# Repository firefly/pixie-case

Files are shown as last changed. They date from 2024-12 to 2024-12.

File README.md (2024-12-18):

Firefly Pixie: Case
===================

Clam Shell
----------

A simple two-part case, meant to be easy to assemble and mass
produce, providing full protection to the PCB, display and buttons.

Harness
-------

The harness is meant to be the simplest MVP of cases, designed to
be easy to assemble and disassemble to swap out boards, replace
screens and test basic components like the buttons and USB-C port
for durability.

It provides sufficient protection to the PCB, display and buttons
for development purposes.

<p align="center">
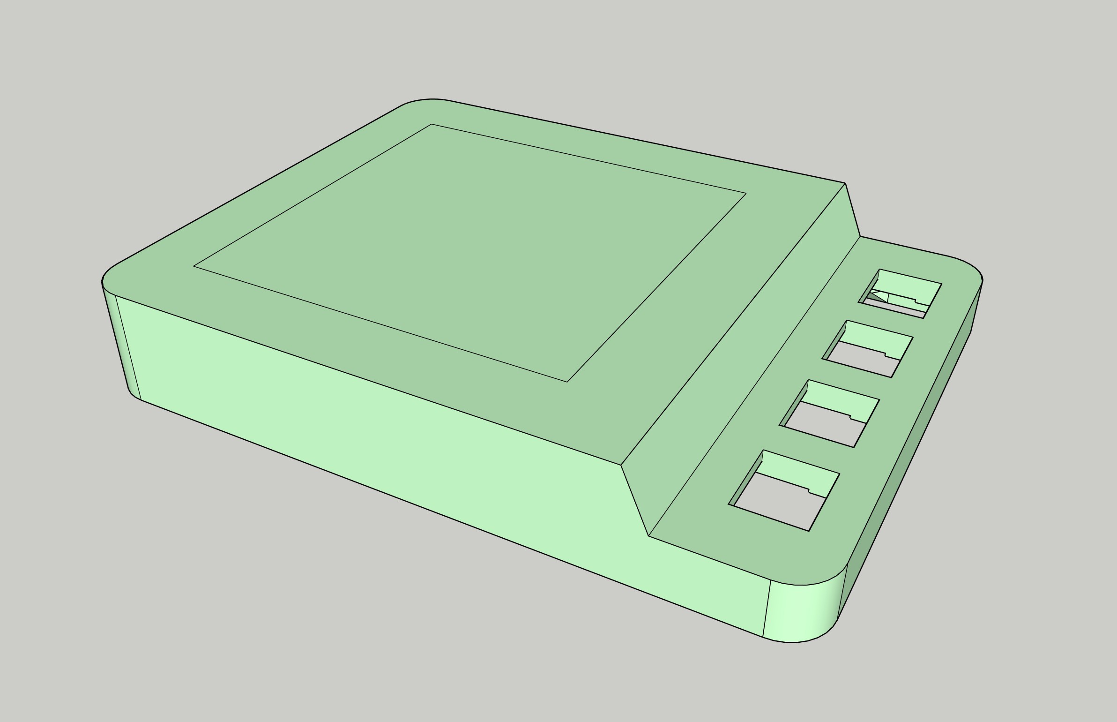
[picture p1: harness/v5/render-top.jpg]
Harness Top View
  
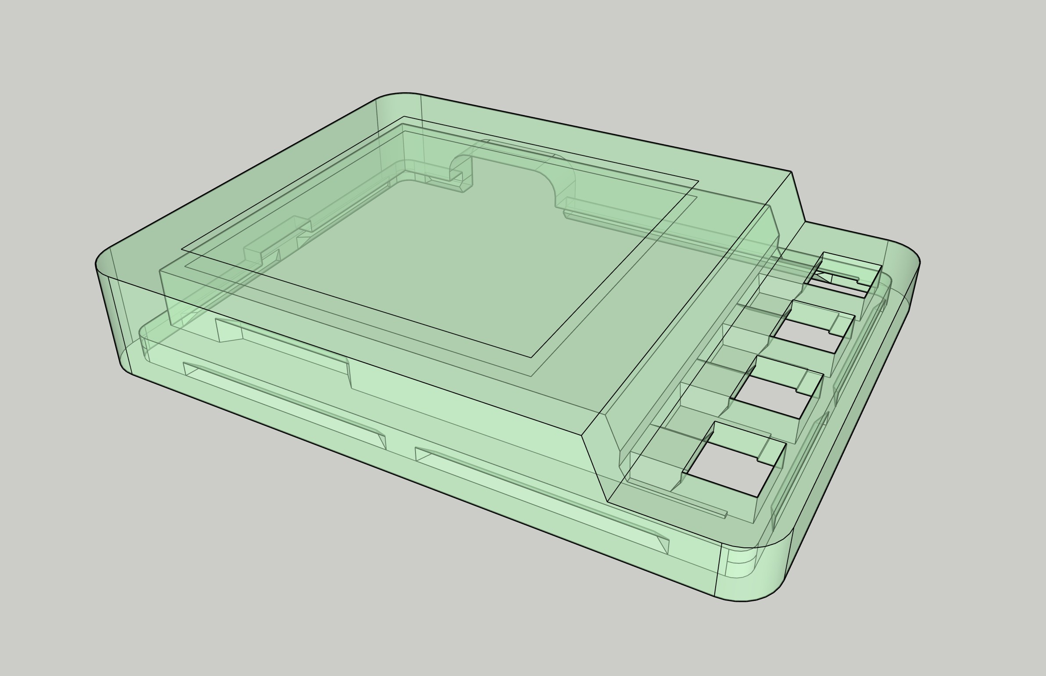
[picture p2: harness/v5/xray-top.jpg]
Harness Top X-ray View
  
</p>

<p align="center">
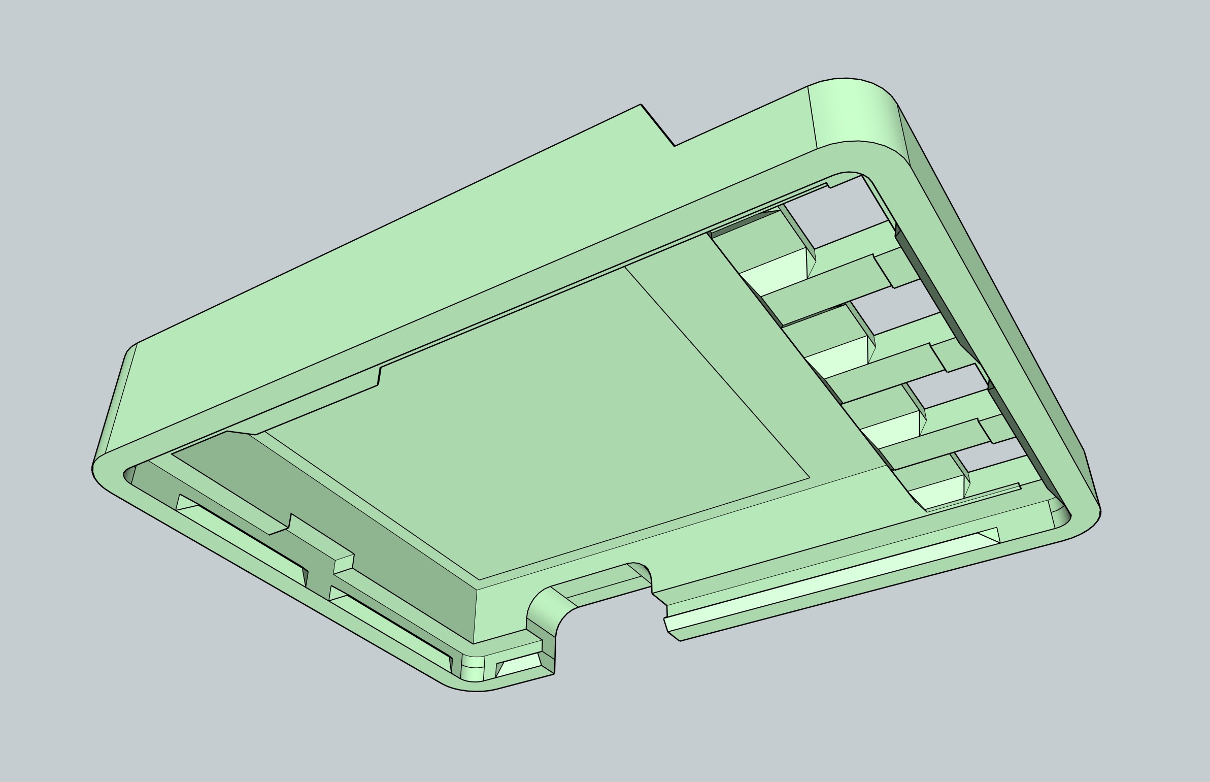
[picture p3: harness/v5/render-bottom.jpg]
Harness Bottom View
  
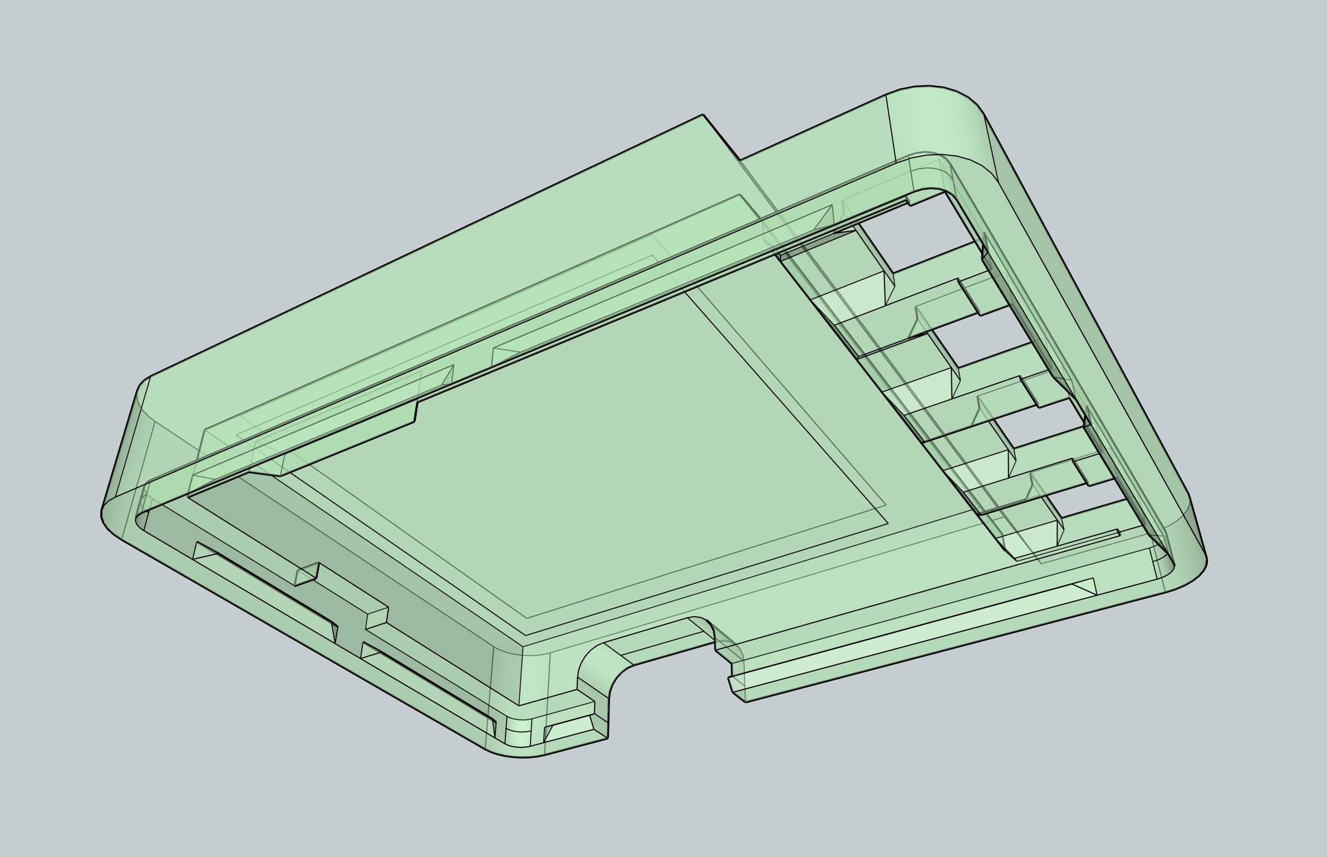
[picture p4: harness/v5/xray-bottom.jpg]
Harness Bottom X-ray View
  
</p>

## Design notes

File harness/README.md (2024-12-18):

Pixie Harness
=============

The Harness is a simple snap-fit case designed to provide minimum
viable protection and operation for devlopers to work with the
device until a more firm case can be designed.

The hardness is 3D printed in 8001 clear resin and snap-fits the
LCD and PCB.

The STL files are prepared for printing, with the `-opaque` variant
having the screen area knocked-out so that it can be printed in an
opaque material with the display still visible.

Renders
-------

<p align="center">
  Harness Top View
  Harness Top X-ray View
</p>

<p align="center">
  Harness Bottom View
  Harness Bottom X-ray View
</p>

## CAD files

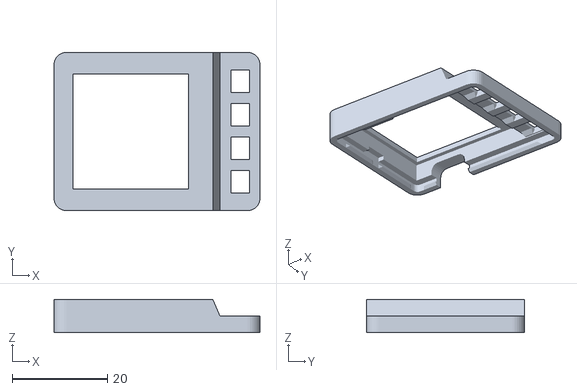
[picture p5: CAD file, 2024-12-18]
harness/v5/harness-opaque.stl
43.2 x 33.2 x 7.00

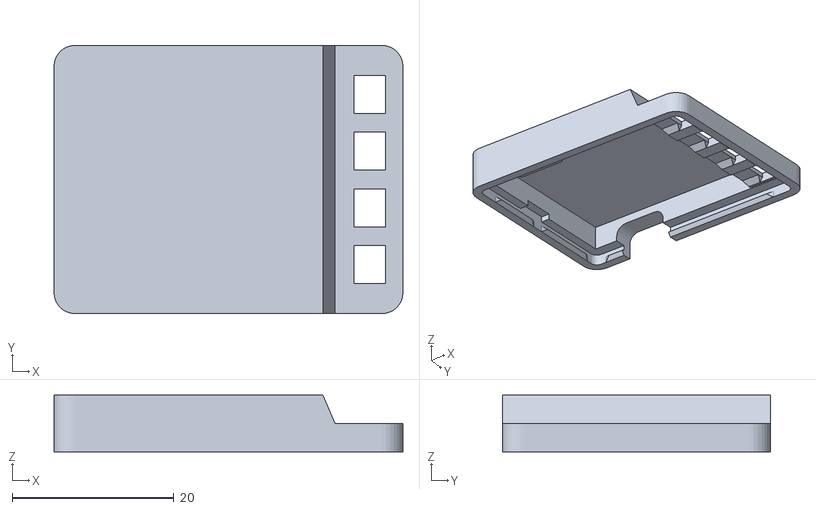
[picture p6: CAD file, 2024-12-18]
harness/v5/harness.stl
43.2 x 33.2 x 7.00

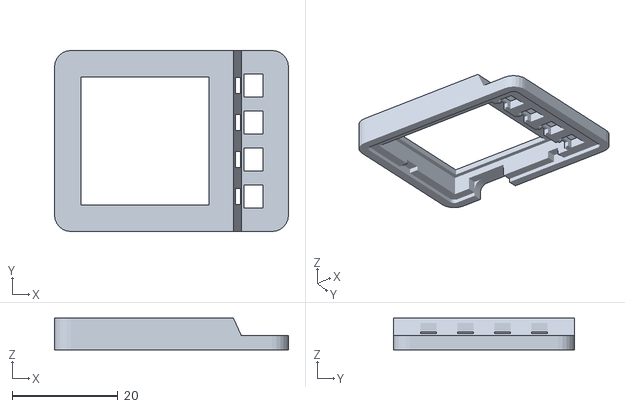
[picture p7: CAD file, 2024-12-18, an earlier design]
harness/v1/harness-opaque.stl
44.2 x 34.2 x 6.00

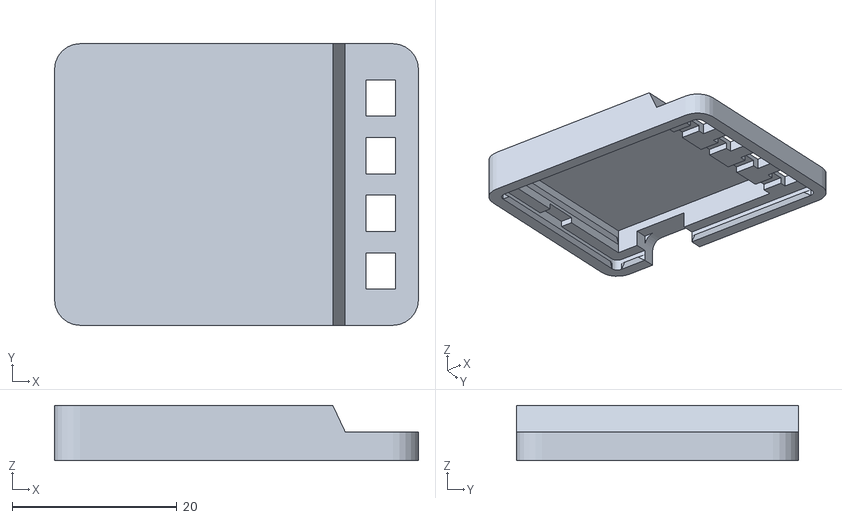
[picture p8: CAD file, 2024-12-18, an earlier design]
harness/v2/harness.stl
44.2 x 34.2 x 6.70

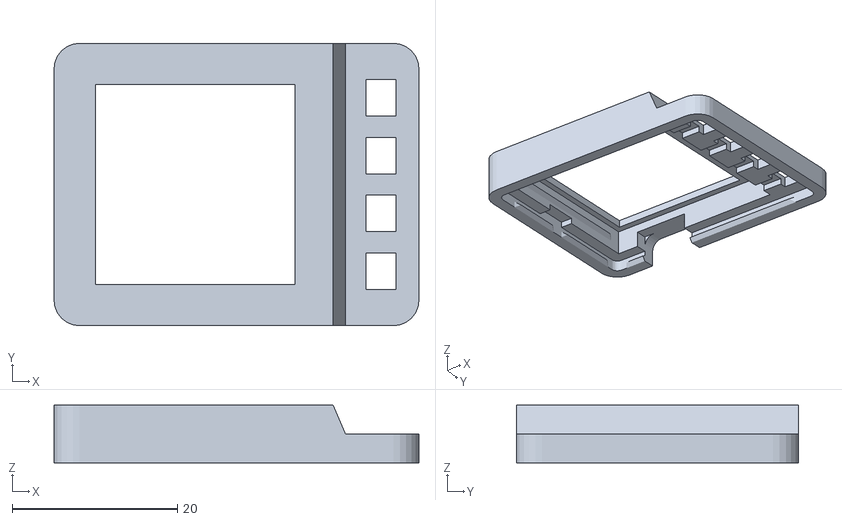
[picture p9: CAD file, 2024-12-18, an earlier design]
harness/v3/harness-opaque.stl
44.2 x 34.2 x 7.00

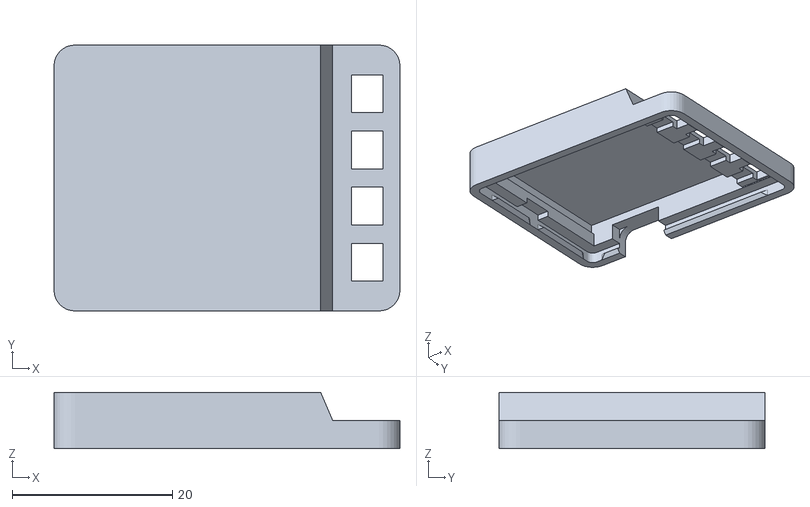
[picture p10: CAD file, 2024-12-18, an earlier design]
harness/v4/harness.stl
43.2 x 33.2 x 7.00

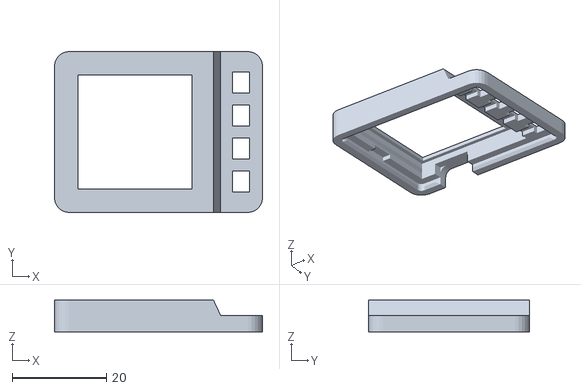
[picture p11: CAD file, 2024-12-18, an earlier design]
harness/v2/harness-opaque.stl
44.2 x 34.2 x 6.70

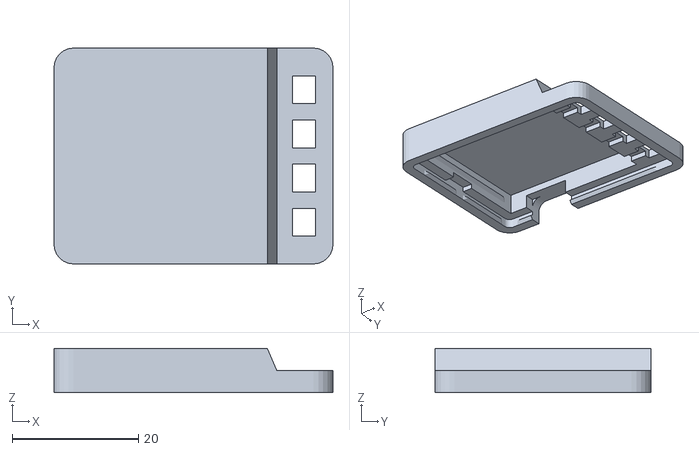
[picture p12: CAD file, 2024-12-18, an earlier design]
harness/v3/harness.stl
44.2 x 34.2 x 7.00

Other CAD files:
harness/v4/harness-opaque.stl
clamshell/clamshell.skp
harness/v1/harness.skp
harness/v2/harness.skp
harness/v3/harness.skp
harness/v4/harness.skp
harness/v5/harness.skp

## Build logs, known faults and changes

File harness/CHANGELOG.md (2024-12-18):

Changelog
=========

Since SketchUP files don't diff well, this log serves as a history of
the changes made between harness versions.

v5; 2024-10-06
--------------

- Remove display end retaining ledge and add display retaining nib

v4; 2024-08-24
--------------

- Added deeper retaining ledge.
- Increased gap around buttons.

v3; 2024-06-25
--------------

- Move display cover back to 1.2mm as there was a triangle of warping near the USB port in it
- Extend the top and bottom wall for the LCD 0.1mm since the fir was very snug
- Use 0.5mm tabs (v3 experimented with 0, 0.5 and 1mm; 0.5 worked well)
- Move tabs (board and LCD) further from the corners which made board insertion crack the nibs
- Broke board tabs into multiple sections for simpler assembly

v2; 2024-06-21
--------------

- Extend the case 1mm past the bottom of the board and add snap fit clips
- Move buttons and LEDs 2mm towards the right edge (reflected in the rev.6 PCB)
- Reduce the thickness between the PCB and top of button shelf, which interferes with button travel
- Remove LED holes, since the 8001 clear resin is clear enough
- Add sill for display; optionally add nibs

v1; 2024-06-04
--------------

- Initial design after many reported concerns by the printhouse (JLCPCB)
- The goal is to have a backup MVP
- The initial print tests the transparency of the 8001 clear resin
- Two versions; with a display hole (printed in multiple colors) and without a display hole (only with transparent resin)

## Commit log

2024-06-05 Added harness; received 2024-06-04
    [harness.skp]
2024-06-05 Added clamshell; received 2024-06-04
    [clamshell.skp]
2024-07-09 Updated harness files.
    [harness-1.skp, harness-2.skp, harness-3.skp]
2024-12-18 Move harness versions into their own folders.
    [harness.skp]
2024-12-18 Added v4 and v5 harness.
    [harness.skp]
2024-12-18 Added STL files.
    [harness-opaque.stl, harness.stl]
